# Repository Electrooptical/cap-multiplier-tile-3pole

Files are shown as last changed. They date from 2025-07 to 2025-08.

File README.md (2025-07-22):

# Capacitance Multiplier Board
This is a 3-pole capacitance multiplier board for use with low noise instruments.
You sacrifice about a volt but get an incredibly quiet power supply.
This layout is intended to be used as a module and soldered to a target board using the castellated holes.

+ 3 Pole power supply filtering
+ Bipolar supplies up to +-20V. 
+ Reverse polarity protection
+ Extreme rejection of switch mode power supply frequencies

Used in our:

+ Low noise amplifiers
+ High gain photoreceivers
+ Low noise laser drivers

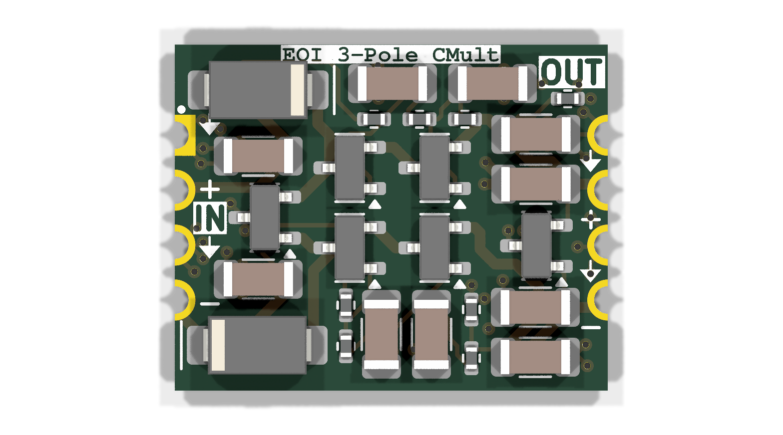
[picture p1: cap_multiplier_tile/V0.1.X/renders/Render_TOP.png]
Board render top

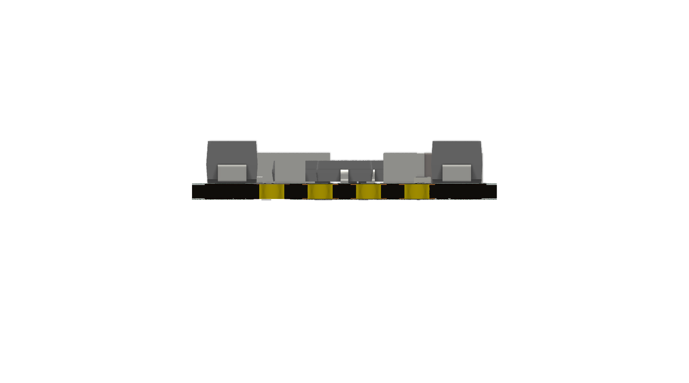
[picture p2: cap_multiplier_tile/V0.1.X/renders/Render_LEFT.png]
Board render left

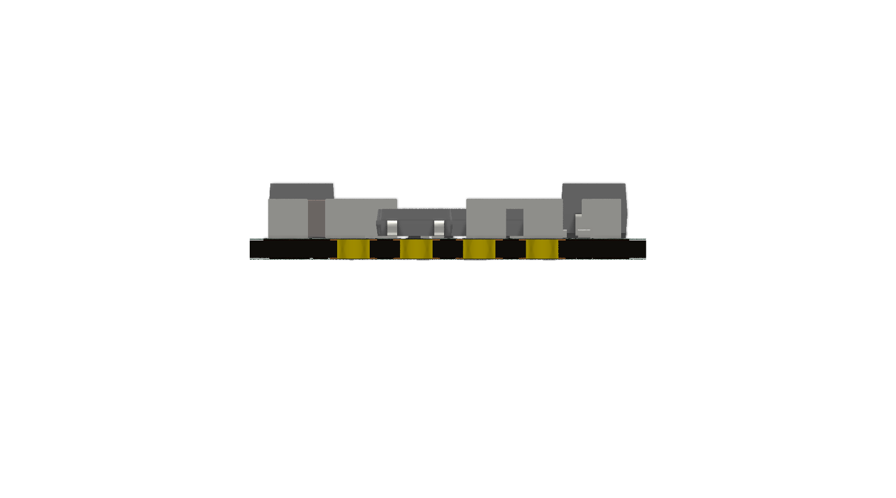
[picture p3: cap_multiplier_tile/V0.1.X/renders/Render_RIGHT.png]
Board render right

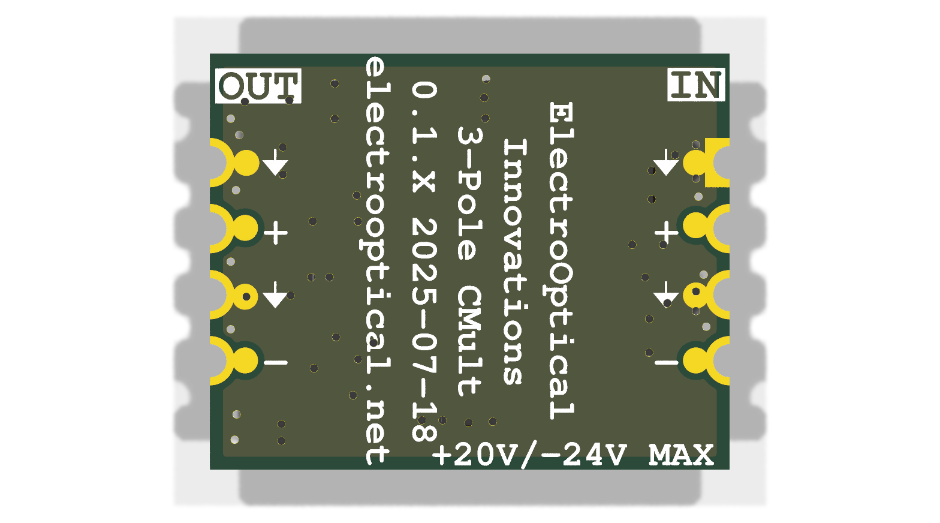
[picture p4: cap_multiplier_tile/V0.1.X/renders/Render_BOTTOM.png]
Board render bottom


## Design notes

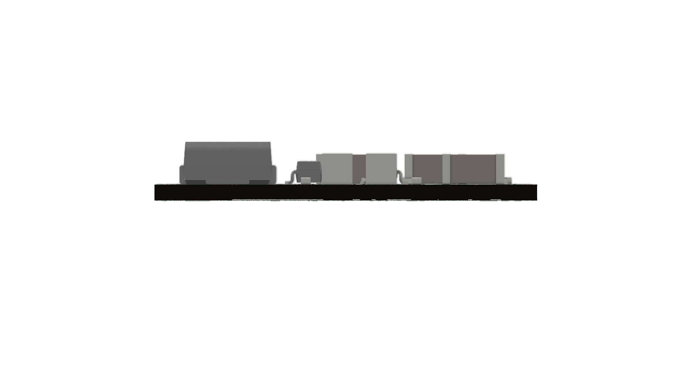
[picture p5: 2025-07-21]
cap_multiplier_tile/V0.1.X/renders/Render_FRONT.png

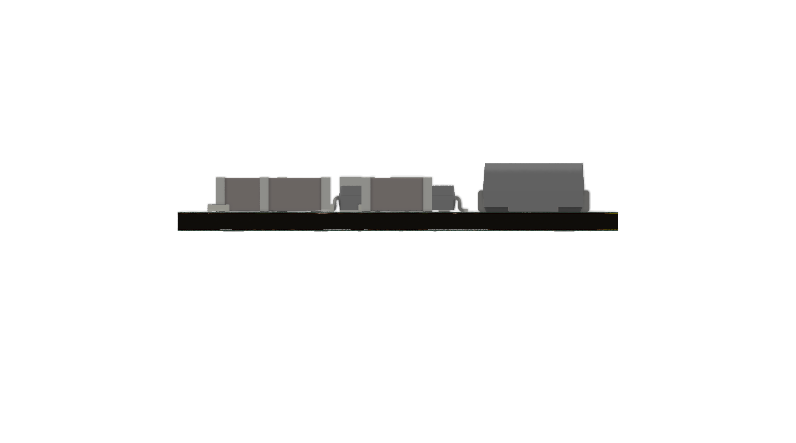
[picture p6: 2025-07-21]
cap_multiplier_tile/V0.1.X/renders/Render_BACK.png

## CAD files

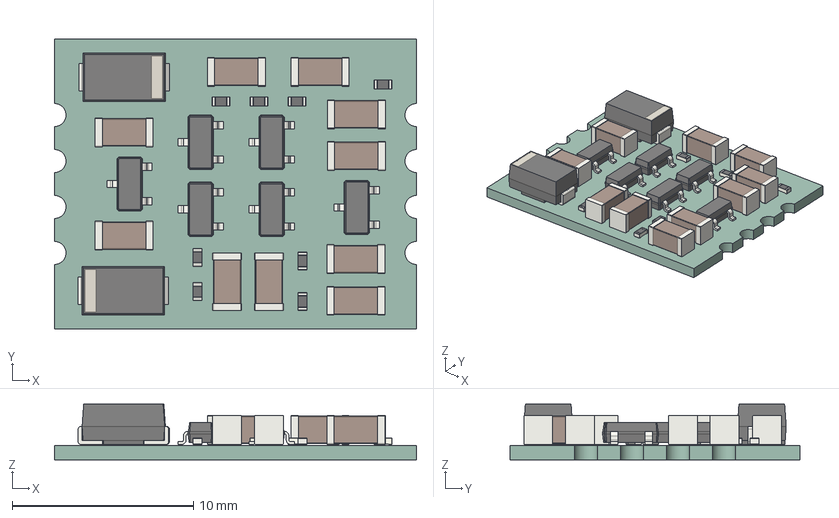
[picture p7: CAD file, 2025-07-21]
cap_multiplier_tile/V0.1.X/0.1.X-2025-07-20/mechanical/cap_multiplier_tile_0.1.X.step
20.0 x 16.0 x 3.07 mm
R_0402_1005Metric x 8
C_1206_3216Metric x 10
SOT_23 x 6
D_SMA x 2
cap_multiplier_tile_PCB

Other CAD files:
cap_multiplier_tile/V0.1.X/board-outline.FCStd
cap_multiplier_tile/V0.1.X/cap_multiplier_tile-drawing.FCStd

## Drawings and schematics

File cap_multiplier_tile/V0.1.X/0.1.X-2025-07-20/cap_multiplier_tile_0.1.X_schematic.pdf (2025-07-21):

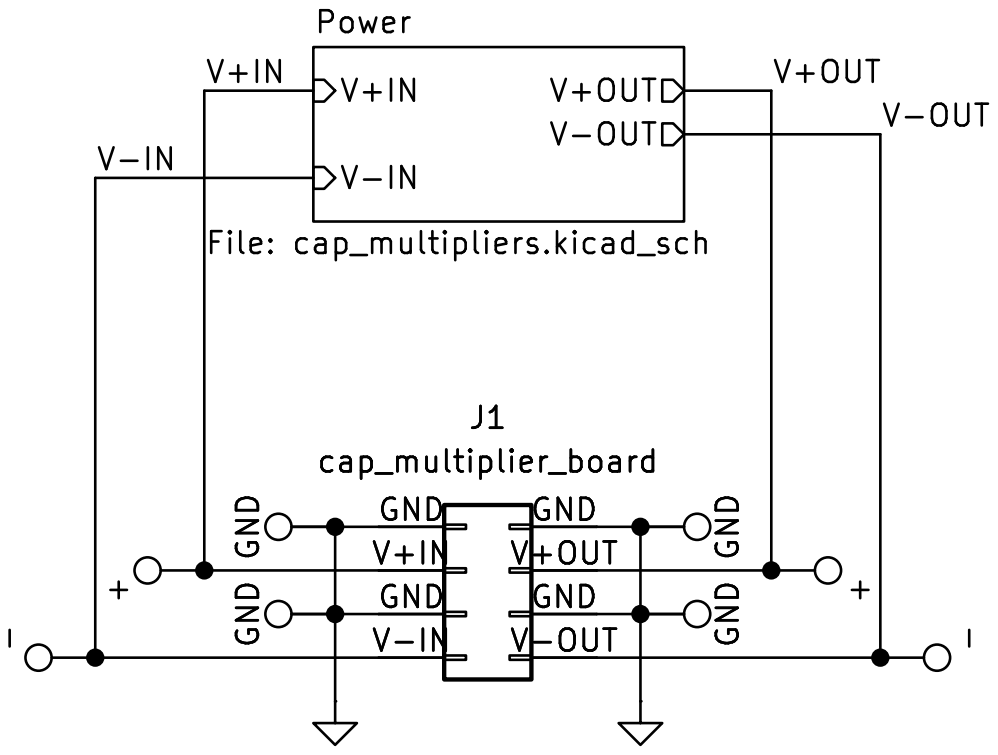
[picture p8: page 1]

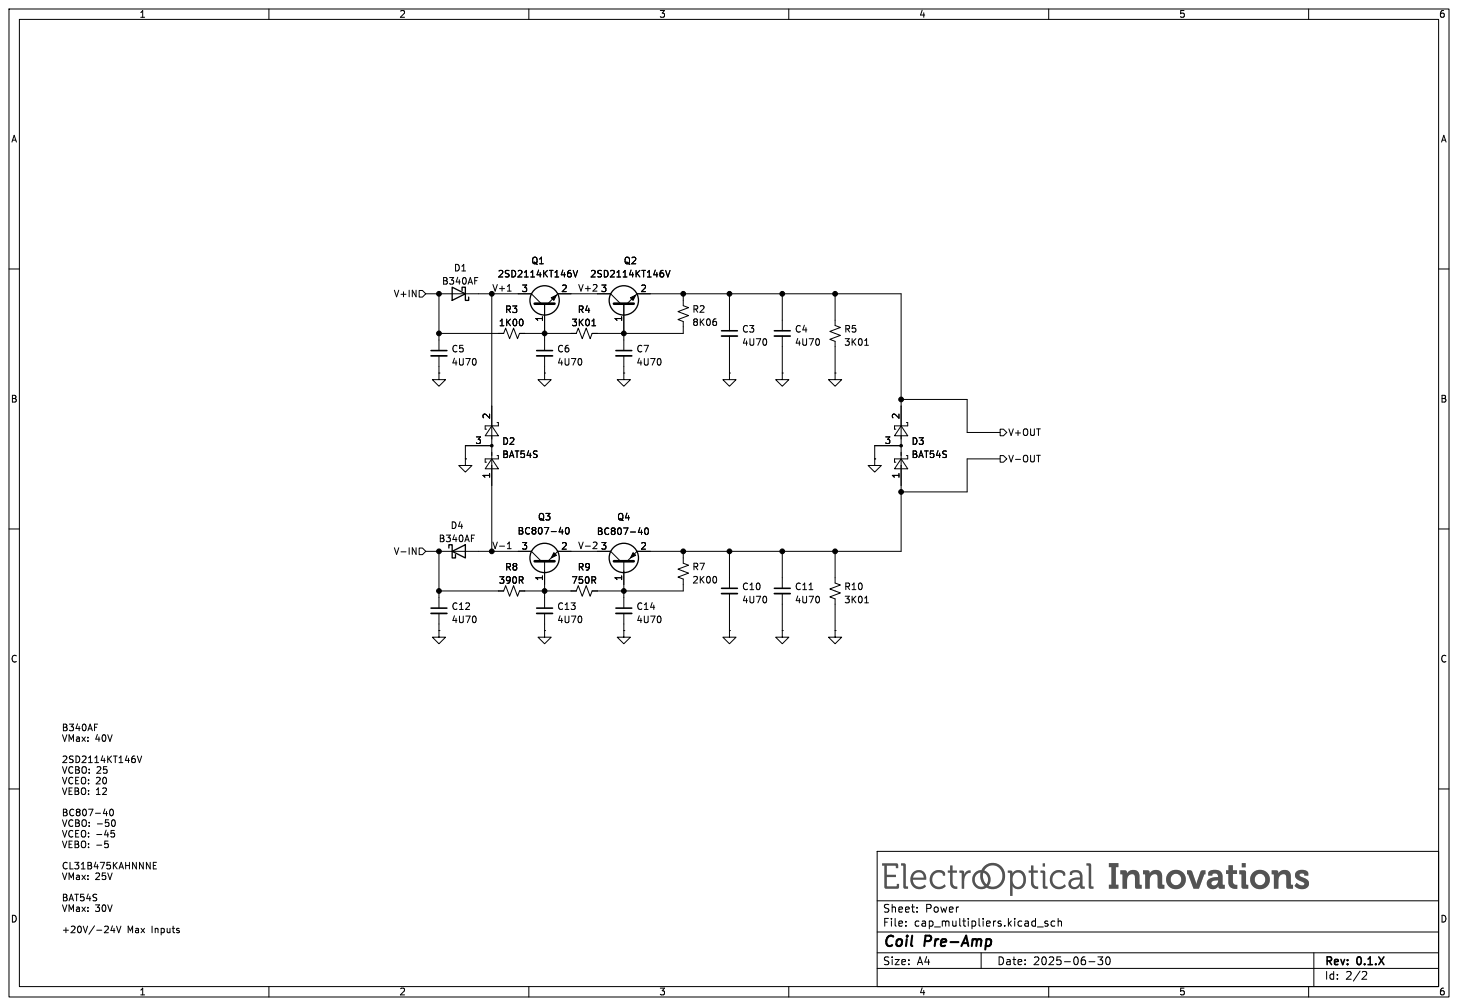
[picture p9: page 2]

VCBO: 25 VCEO: 20 VEBO: 12 BC807-40 VCBO: -50 VCEO: -45 VEBO: -5 CL31B475KAHNNNE

Id: 2/2 Coil Pre-Amp

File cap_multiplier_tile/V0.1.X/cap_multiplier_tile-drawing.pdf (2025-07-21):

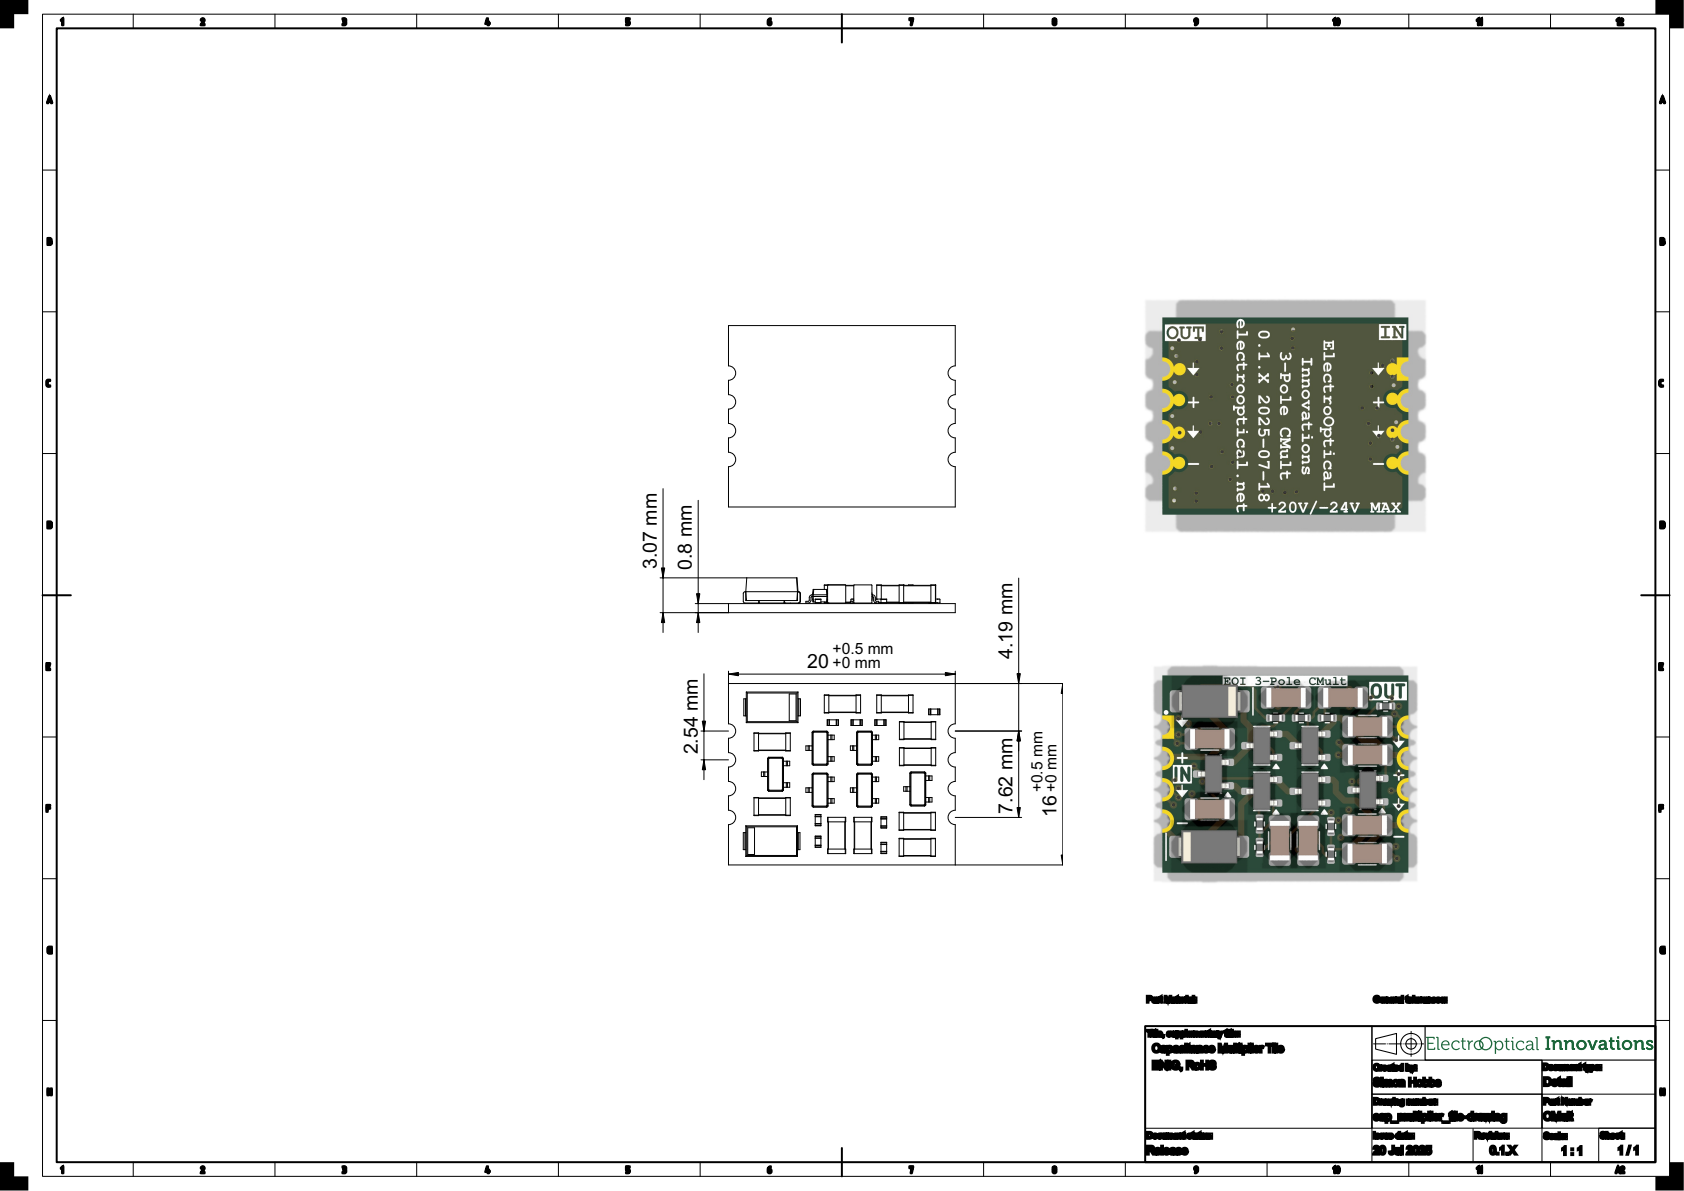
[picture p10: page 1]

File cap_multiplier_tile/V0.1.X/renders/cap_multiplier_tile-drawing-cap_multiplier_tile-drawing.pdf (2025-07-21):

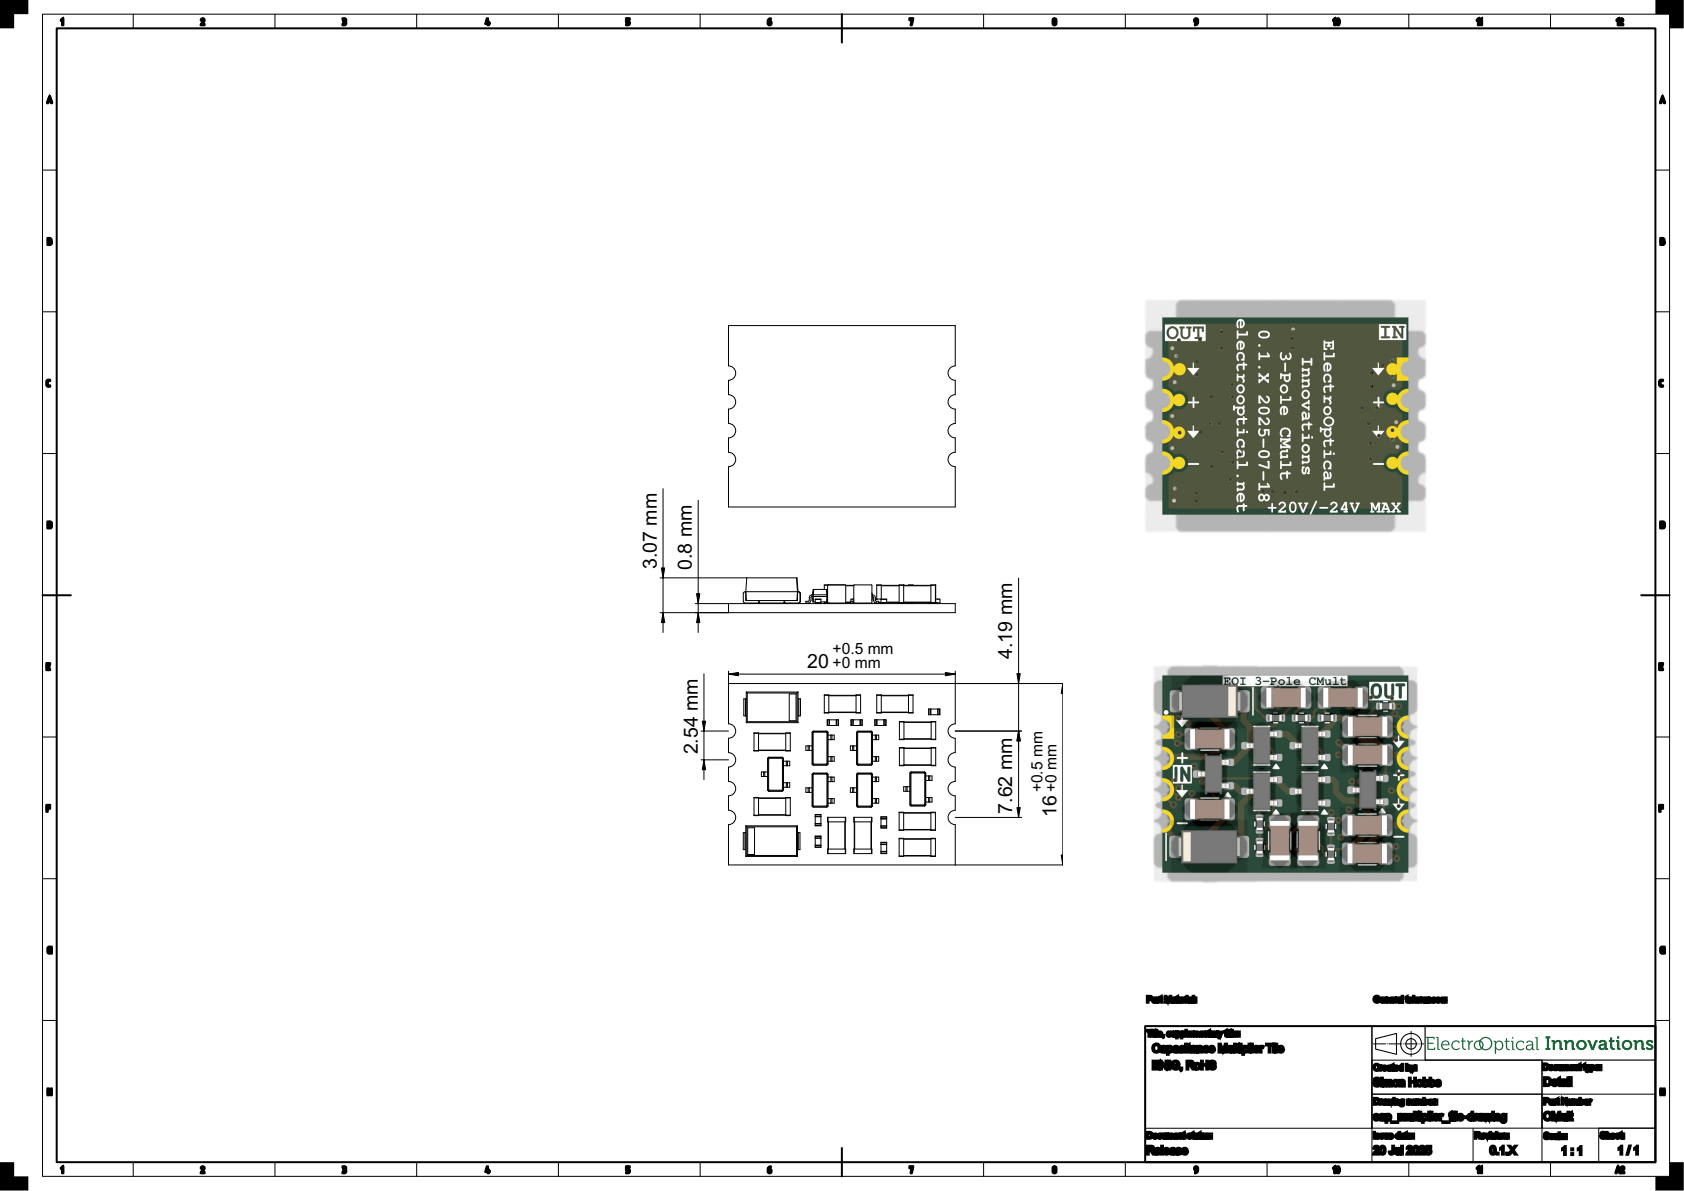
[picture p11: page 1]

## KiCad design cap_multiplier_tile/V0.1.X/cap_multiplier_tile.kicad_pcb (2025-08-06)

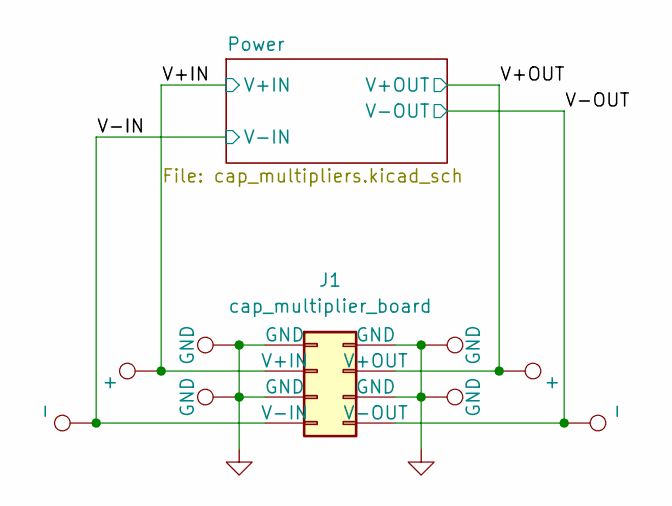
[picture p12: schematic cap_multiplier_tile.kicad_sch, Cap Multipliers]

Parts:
J1: cap_multiplier_board; board
TP1, TP7: +; TestPoint_Pad_D1.0mm
TP2, TP8: -; TestPoint_Pad_D1.0mm
TP3, TP4, TP5, TP6: GND; TestPoint_Pad_D1.0mm

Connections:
/V+IN: J1.2 (V+IN), TP7.1; also elsewhere on the board
/V+OUT: J1.7 (V+OUT), TP1.1; also elsewhere on the board
/V-IN: J1.4 (V-IN), TP8.1; also elsewhere on the board
/V-OUT: J1.5 (V-OUT), TP2.1; also elsewhere on the board
GND: J1.1 (GND), J1.3 (GND), J1.6 (GND), J1.8 (GND), TP3.1, TP4.1, TP5.1, TP6.1; also elsewhere on the board

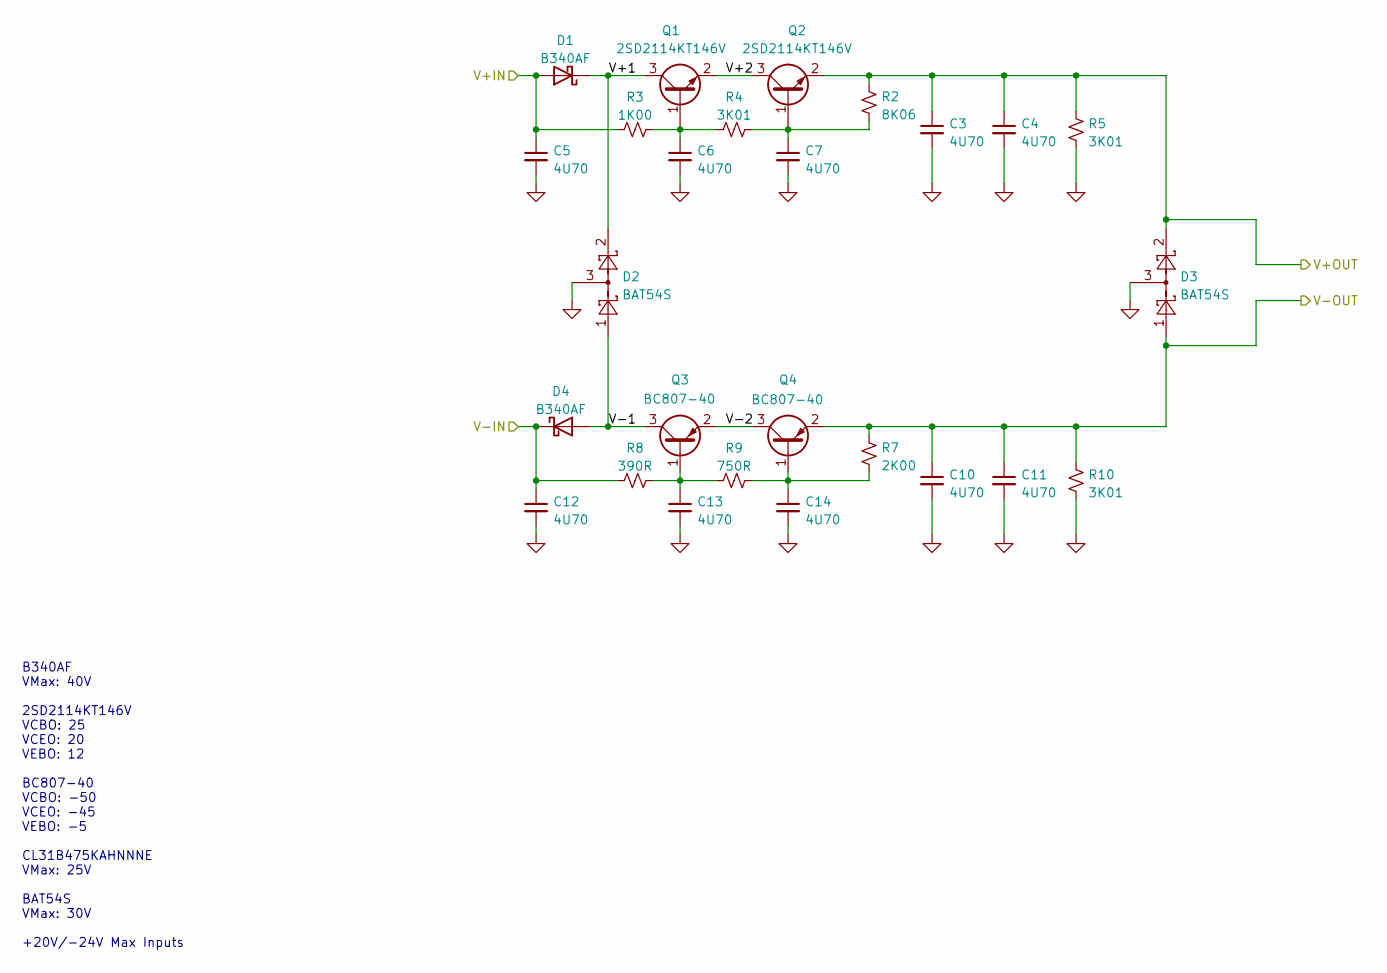
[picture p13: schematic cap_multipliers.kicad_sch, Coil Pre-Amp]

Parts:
C3, C4, C5, C6, C7, C10, C11, C12, C13, C14: 4U70; C_1206_3216Metric; LCSC C1872
D1, D4: B340AF; D_SMA; LCSC C85098
D2, D3: BAT54S; SOT-23; LCSC C377935
Q1, Q2: 2SD2114KT146V; SOT-23; LCSC C308659
Q3, Q4: BC807-40; SOT-23; LCSC C57316
R2: 8K06; R_0402_1005Metric
R3: 1K00; R_0402_1005Metric
R4, R5, R10: 3K01; R_0402_1005Metric
R7: 2K00; R_0402_1005Metric
R8: 390R; R_0402_1005Metric
R9: 750R; R_0402_1005Metric

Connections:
/Power/V+1: D1.1 (K), D2.2 (K), Q1.3 (C)
/Power/V+2: Q1.2 (E), Q2.3 (C)
/Power/V-1: D2.1 (A), D4.2 (A), Q3.3 (C)
/Power/V-2: Q3.2 (E), Q4.3 (C)
/V+IN: C5.1, D1.2 (A), R3.1; also elsewhere on the board
/V+OUT: C3.1, C4.1, D3.2 (K), Q2.2 (E), R2.2, R5.2; also elsewhere on the board
/V-IN: C12.1, D4.1 (K), R8.1; also elsewhere on the board
/V-OUT: C10.1, C11.1, D3.1 (A), Q4.2 (E), R7.2, R10.2; also elsewhere on the board
GND: C3.2, C4.2, C5.2, C6.2, C7.2, C10.2, C11.2, C12.2, C13.2, C14.2, D2.3 (COM), D3.3 (COM), R5.1, R10.1; also elsewhere on the board
unnamed: C6.1, Q1.1 (B), R3.2, R4.1
unnamed: C7.1, Q2.1 (B), R2.1, R4.2
unnamed: C13.1, Q3.1 (B), R8.2, R9.1
unnamed: C14.1, Q4.1 (B), R7.1, R9.2

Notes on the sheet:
B340AF VMax: 40V 2SD2114KT146V VCBO: 25 VCEO: 20 VEBO: 12 BC807-40 VCBO: -50 VCEO: -45 VEBO: -5 CL31B475KAHNNNE VMax: 25V BAT54S VMax: 30V +20V/-24V Max Inputs

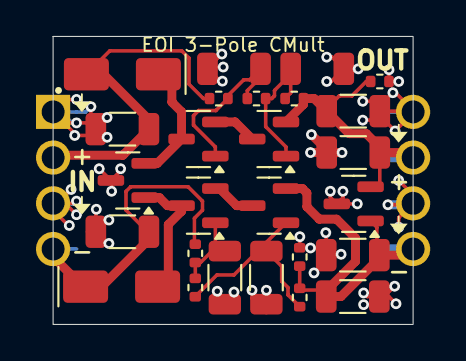
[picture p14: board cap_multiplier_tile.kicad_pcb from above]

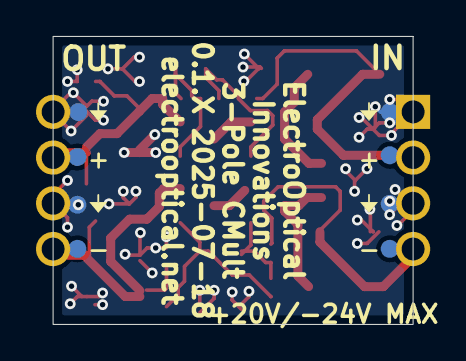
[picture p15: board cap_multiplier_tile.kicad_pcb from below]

Board: 2 copper layers, 20.0 x 16.0 mm, 35 parts (8 on the bottom side), 13 nets.
